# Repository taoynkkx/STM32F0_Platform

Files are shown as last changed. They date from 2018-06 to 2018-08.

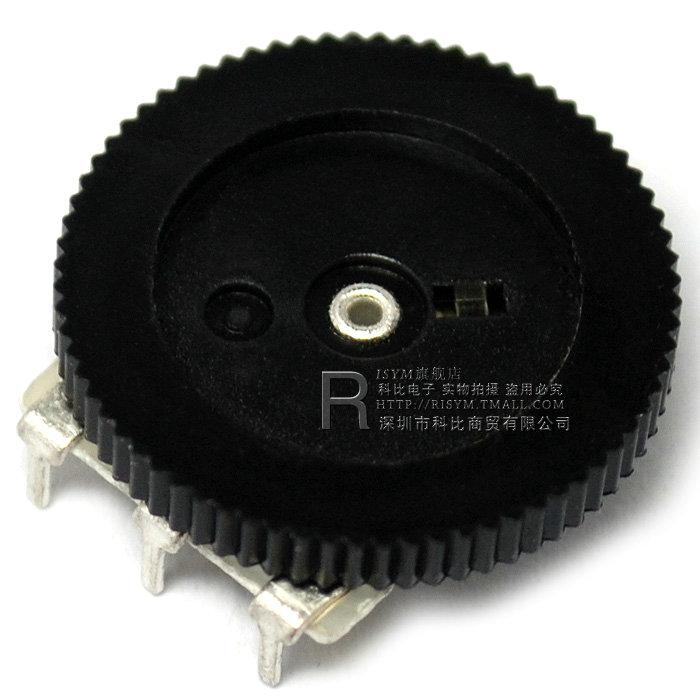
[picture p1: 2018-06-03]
010_Hardware/030_Datasheets/Potentiometer2.jpg

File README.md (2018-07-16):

# STM32F0 Platform

This project begins with designing a simple development board with the chip STM32F072C8T6.

## The platform hardware will include the following peripherals

- 4 buttons: BOOT0, RESET, WAKEUP1, WAKEUP2
- 2 potentiometers (@ ADC_IN8/9)
- 2 crystals: 12MHz, 32.768KHz
- Cell battery
- TF Card (@ SPI1)
- EEPROM (AT24C256 @ IIC1)
- USB-UART converter (PL2303 @ USART1)
- LIN transceiver (TJA1020 @ USART2)
- RS485 transceiver (SP485 @ USART3)
- CAN transceiver (TJA1050 @ CAN)
- USB connector ( @ DP+DM)
- SW debug ports (SWDIO+SWCLK)
- 4 LEDs, with PWM duty control
- 18B20
- not used PINs will be left with connectors

## With these the following features can supported

- STLink connection: SWDIO, SWCLK, RESET
- FlashLoaderDemo: RESET, BOOT0, USART1 or USB(DP+DM)
- Low power mode: WAKEUP1, WAKEUP2
- RTC: cell battery, 32.768KHz crystal
- Backup: cell battery
- USB device.

### Software is going to port all interesting examples from the official library examples, as the first step.

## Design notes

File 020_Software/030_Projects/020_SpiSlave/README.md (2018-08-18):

SPI Slave

This software is to receive data as SPI slave, and then send SPI data to PC via UART.

This is used to analyze the behavior of user software, which is printing run time information from SPI.

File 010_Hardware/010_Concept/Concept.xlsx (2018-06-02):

reset button
boot button

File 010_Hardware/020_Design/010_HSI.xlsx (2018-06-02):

LQFP48 | Pin Name | Pin Type | IO Structure | Notes | AF0 | AF1 | AF2 | AF3 | AF4 | AF5 | AF6 | AF7 | Additional functions | Comments | Use as | Use for | Polarity | LED
1 | VBAT | S |  |  |  |  |  |  |  |  |  |  |  | Backup power supply | VBAT
2 | PC13 | IO | TC | 1,2 |  |  |  |  |  |  |  |  | WKUP2, RTC_TAMP1, RTC_TS, RTC_OUT |  | WKUP2 | Wake Up | High Active
3 | PC14-OSC32_IN(PC14) | IO | TC | 1,2 |  |  |  |  |  |  |  |  | OSC32_IN |  | OSC32_IN
4 | PC15-OSC32_OUT(PC15) | IO | TC | 1,2 |  |  |  |  |  |  |  |  | OSC32_OUT |  | OSC32_OUT
5 | PF0-OSC_IN(PF0) | IO | FT |  |  |  |  |  |  |  |  |  | OSC_IN |  | OSC_IN
6 | PF1-OSC_OUT(PF1) | IO | FT |  |  |  |  |  |  |  |  |  | OSC_OUT |  | OSC_OUT
7 | NRST | IO | RST |  |  |  |  |  |  |  |  |  |  | Device reset input / internal reset output (active low) | Reset
8 | VSSA | S |  |  |  |  |  |  |  |  |  |  |  | Analog ground | GND
9 | VDDA | S |  |  |  |  |  |  |  |  |  |  |  | Analog power supply | VDDA
10 | PA00 | IO | FT |  |  | USART2_CTS | TIM2_CH1_ETR | TSC_G1_IO1 | USART4_TX |  |  | COMP1_OUT | RTC_TAMP2, WKUP1, ADC_IN0, COMP1_INM6 |  | WKUP1 | Wake up | High Active
11 | PA01 | IO | TTa |  | EVENTOUT | USART2_RTS | TIM2_CH2 | TSC_G1_IO2 | USART4_RX | TIM15_CH1N |  |  | ADC_IN1, COMP1_INP
12 | PA02 | IO | TTa |  | TIM15_CH1 | USART2_TX | TIM2_CH3 | TSC_G1_IO3 |  |  |  | COMP2_OUT | ADC_IN2, COMP2_INM6, WKUP4 |  | AF1: TX2 | LIN |  | YES
13 | PA03 | IO | TTa |  | TIM15_CH2 | USART2_RX | TIM2_CH4 | TSC_G1_IO4 |  |  |  |  | ADC_IN3, COMP2_INP |  | AF1: RX2 | LIN
14 | PA04 | IO | TTa |  | SPI1_NSS, I2S1_SW | USART2_CK |  | TSC_G2_IO1 | TIM14_CH1 |  |  |  |  |  |  | SPI
15 | PA05 | IO | TTa |  | SPI1_SCK, I2S1_CK | CEC | TIM2_CH1_ETR | TSC_G2_IO2 |  |  |  |  |  |  |  | SPI
16 | PA06 | IO | TTa |  | SPI1_MISO, I2S1_MCK | TIM3_CH1 | TIM1_BKIN | TSC_G2_IO3 | USART3_CTS | TIM16_CH1 | EVENTOUT | COMP1_OUT |  |  |  | SPI
17 | PA07 | IO | TTa |  | SPI1_MOSI, I2S1_SD | TIM3_CH2 | TIM1_CH1N | TSC_G2_IO4 | TIM14_CH1 | TIM17_CH1 | EVENTOUT | COMP2_OUT |  |  |  | SPI
18 | PB00 | IO | TTa |  | EVENTOUT | TIM3_CH3 | TIM1_CH2N | TSC_G3_IO2 | USART3_CK |  |  |  | ADC_IN8 |  | ADC_IN8 | ADC
19 | PB01 | IO | TTa |  | TIM14_CH1 | TIM3_CH4 | TIM1_CH3N | TSC_G3_IO3 | USART3_RTS |  |  |  | ADC_IN9 |  | ADC_IN9 | ADC
20 | PB02 | IO | FT |  |  |  |  | TSC_G3_IO4
21 | PB10 | IO | FT |  | CEC | I2C2_SCL | TIM2_CH3 | TSC_SYNC | USART3_TX | SPI2_SCK, I2S2_CK |  |  |  |  | AF4: TX3 | RS485 |  | YES
22 | PB11 | IO | FT |  | EVENTOUT | I2C2_SDA | TIM3_CH4 | TSC_G6_IO1 | USART3_RX |  |  |  |  |  | AF4: RX3 | RS485
23 | VSS | S |  |  |  |  |  |  |  |  |  |  |  | Ground | GND
24 | VDD | S |  |  |  |  |  |  |  |  |  |  |  | Digital power supply | VDD
25 | PB12 | IO | FT |  | SPI2_NSS, I2S2_WS | EVENTOUT | TIM1_BKIN | TSC_G6_IO2 | USART3_CK | TIM15_BKIN |  |  |  |  | AF0 | SPI/I2C
26 | PB13 | IO | FTf |  | SPI2_SCK, I2S2_CK |  | TIM1_CH1N | TSC_G6_IO3 | USART3_CTS | I2C2_SCL |  |  |  |  | AF0/AF5 | SPI/I2C
27 | PB14 | IO | FTf |  | SPI2_MISO, I2S2_MCK | TIM15_CH1 | TIM1_CH2N | TSC_G6_IO4 | USART3_RTS | I2C2_SDA |  |  |  |  | AF0/AF5 | SPI/I2C
28 | PB15 | IO | FT |  | SPI2_MOSI, I2S2_SD | TIM15_CH2 | TIM1_CH3N | TIM15_CH1N |  |  |  |  | WKUP7, RTC_REFIN |  | AF0 | SPI/I2C
29 | PA08 | IO | FT | 3 | MCO | USART1_CK | TIM1_CH1 | EVENTOUT | CRS_SYNC
30 | PA09 | IO | FT | 3 | TIM15_BKIN | USART1_TX | TIM1_CH2 | TSC_G4_IO1 |  |  |  |  |  |  | AF1: TX1 | reflash/debug |  | YES
31 | PA10 | IO | FT | 3 | TIM17_BKIN | USART1_RX | TIM1_CH3 | TSC_G4_IO2 |  |  |  |  |  |  | AF1: RX1 | reflash/debug
32 | PA11 | IO | FT | 3 | EVENTOUT | USART1_CTS | TIM1_CH4 | TSC_G4_IO3 | CAN_RX |  |  | COMP1_OUT | USB_DM |  | USB_DM | USB
33 | PA12 | IO | FT | 3 | EVENTOUT | USART1_RTS | TIM1_ETR | TSC_G4_IO4 | CAN_TX |  |  | COMP2_OUT | USB_DP |  | USB_DP | USB
34 | PA13 | IO | FT | 3,4 | SWDIO | IR_OUT | USB_NOE |  |  |  |  |  |  |  | SWDIO | debug
35 | VSS | S |  |  |  |  |  |  |  |  |  |  |  |  | GND
36 | VDDIO2 | S |  |  |  |  |  |  |  |  |  |  |  |  | VDD
37 | PA14 | IO | FT | 3,4 | SWCLK | USART2_TX |  |  |  |  |  |  |  |  | SWCLK | debug
38 | PA15 | IO | FT | 3 | SPI1_NSS, I2S1_WS | USART2_RX | TIM2_CH1_ETR | EVENTOUT | USART4_RTS |  |  |  |  |  | AF0: NSS1 | SFLASH
39 | PB03 | IO | FT |  | SPI1_SCK, I2S1_CK | EVENTOUT | TIM2_CH2 | TSC_G5_IO1 |  |  |  |  |  |  | AF0: SCK1 | SFLASH
40 | PB04 | IO | FT |  | SPI1_MISO, I2S1_MCK | TIM3_CH1 | EVENTOUT | TSC_G5_IO2 |  | TIM17_BKIN |  |  |  |  | AF0: MISO1 | SFLASH
41 | PB05 | IO | FT |  | SPI1_MOSI, I2S1_SD | TIM3_CH2 | TIM16_BKIN | I2C1_SMBA |  |  |  |  | WKUP6 |  | AF0: MOSI1 | SFLASH
42 | PB06 | IO | FT |  | USART1_TX | I2C1_SCL | TIM16_CH1N | TSC_G5_IO3 |  |  |  |  |  |  | AF1: SCL1 | EEP
43 | PB07 | IO | FTf |  | USART1_RX | I2C1_SDA | TIM17_CH1N | TSC_G5_IO4 | USART4_CTS |  |  |  |  |  | AF1: SDA1 | EEP
44 | BOOT0 | I | B |  |  |  |  |  |  |  |  |  |  | Boot memory selection | BOOT | reflash
45 | PB08 | IO | FTf |  | CEC | I2C1_SCL | TIM16_CH1 | TSC_SYNC | CAN_RX |  |  |  |  |  | AF4: CRX | CAN
46 | PB09 | IO | FTf |  | IR_OUT | I2C1_SDA | TIM17_CH1 | EVENTOUT | CAN_TX | SPI2_NSS, I2S2_WS |  |  |  |  | AF4: CTX | CAN |  | YES
47 | VSS | S |  |  |  |  |  |  |  |  |  |  |  | Ground | GND
48 | VDD | S |  |  |  |  |  |  |  |  |  |  |  | Digital power supply | VDD

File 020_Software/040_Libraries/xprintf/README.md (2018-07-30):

This is printf function for microcontroller from elm-chan.org.

Embedded String Functions - http://elm-chan.org/fsw/strf/xprintf.html

This is distributed as Open Source Software. See copyright notice below and
http://elm-chan.org/fsw_e.html.

------------------------------------------------------------------------
  Universal string handler for user console interface
------------------------------------------------------------------------

  Copyright (C) 2011, ChaN, all right reserved.<br>

 * This software is a free software and there is NO WARRANTY.
 * No restriction on use. You can use, modify and redistribute it for personal, non-profit or commercial products UNDER YOUR RESPONSIBILITY.
 * Redistributions of source code must retain the above copyright notice.

-------------------------------------------------------------------------

And xio.h/c is adapted for this project from xprintf.h/c

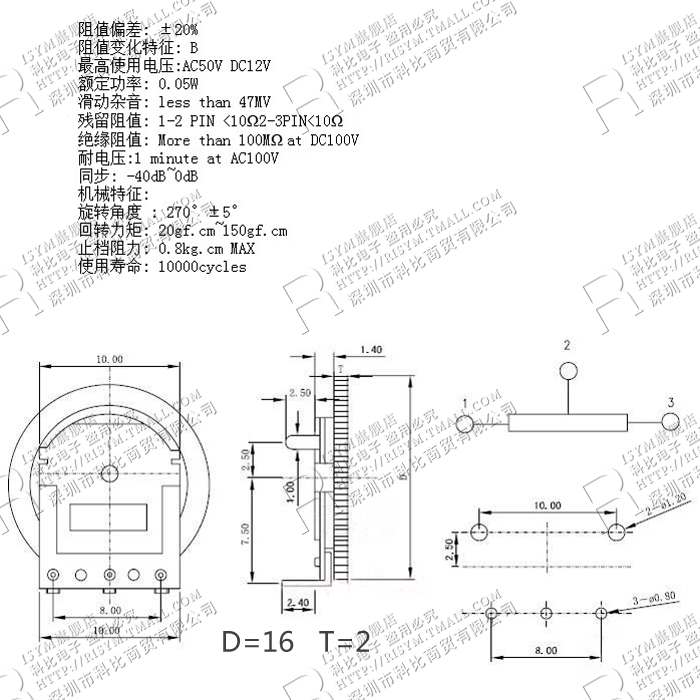
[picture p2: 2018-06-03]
010_Hardware/030_Datasheets/Potentiometer.jpg

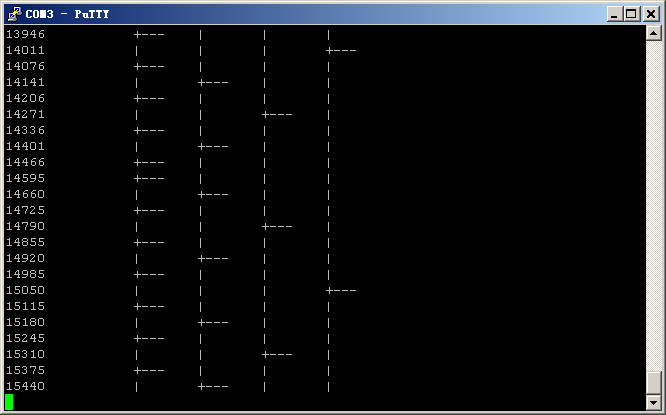
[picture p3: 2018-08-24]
020_Software/030_Projects/000_Template/doc/run.png

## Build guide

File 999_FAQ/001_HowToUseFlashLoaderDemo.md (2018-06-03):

# How to use the official FlashLoaderDemo to download S19/HEX?

- step 1, connect your board via USB(PL) to your computer. (you should have already installed FlashLoaderDemo and PL2303 driver).
- step 2, keep BOOT button pressed, and press RESET button and release RESET, then release BOOT.
- step 3, you should be able to run FlashLoaderDemo and connect to the board.

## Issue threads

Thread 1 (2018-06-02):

[HW] design the schematic and PCB layout.

taoynkkx, 2018-06-02:
Design the schematic and PCB layout.

taoynkkx, 2018-06-03:
split task into new issues: #2, #3, #4, #5.

taoynkkx, 2018-07-21:
done.

Closed 2018-07-21.

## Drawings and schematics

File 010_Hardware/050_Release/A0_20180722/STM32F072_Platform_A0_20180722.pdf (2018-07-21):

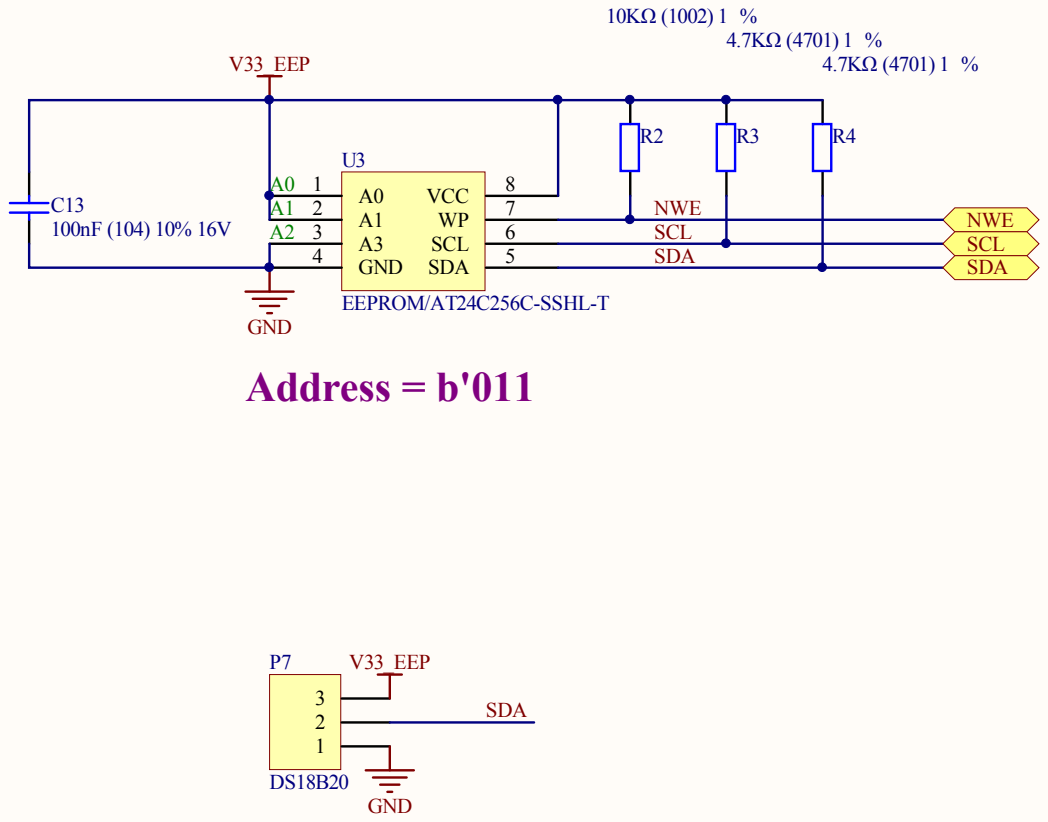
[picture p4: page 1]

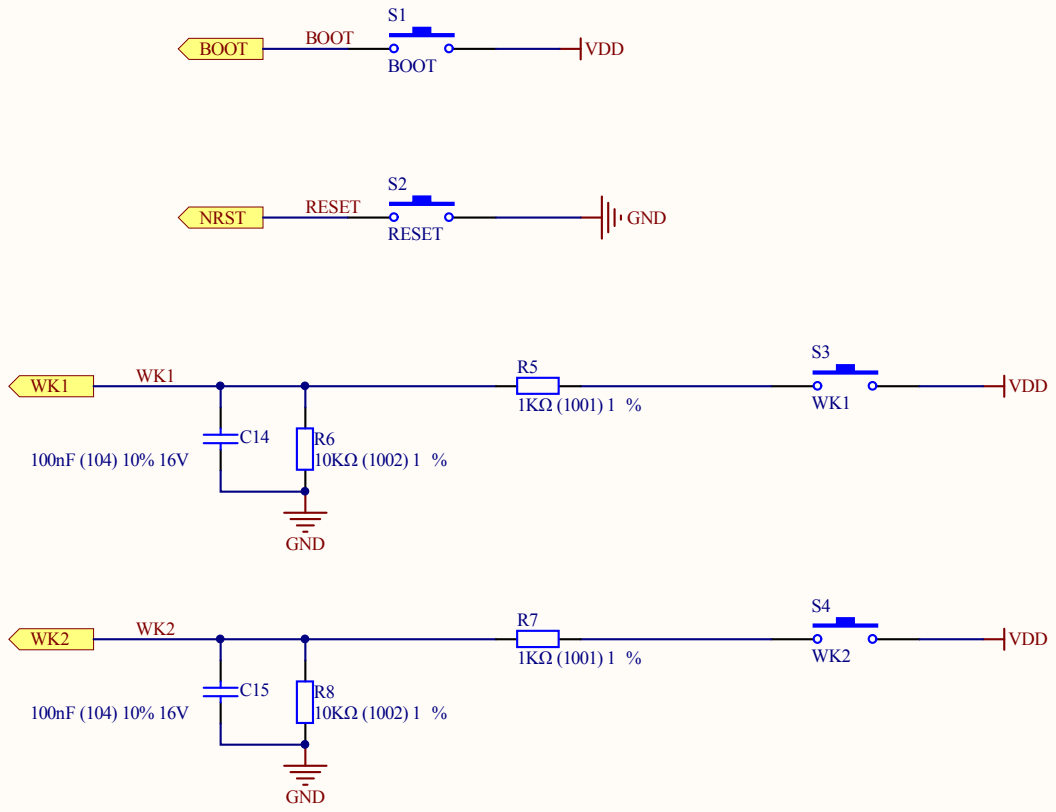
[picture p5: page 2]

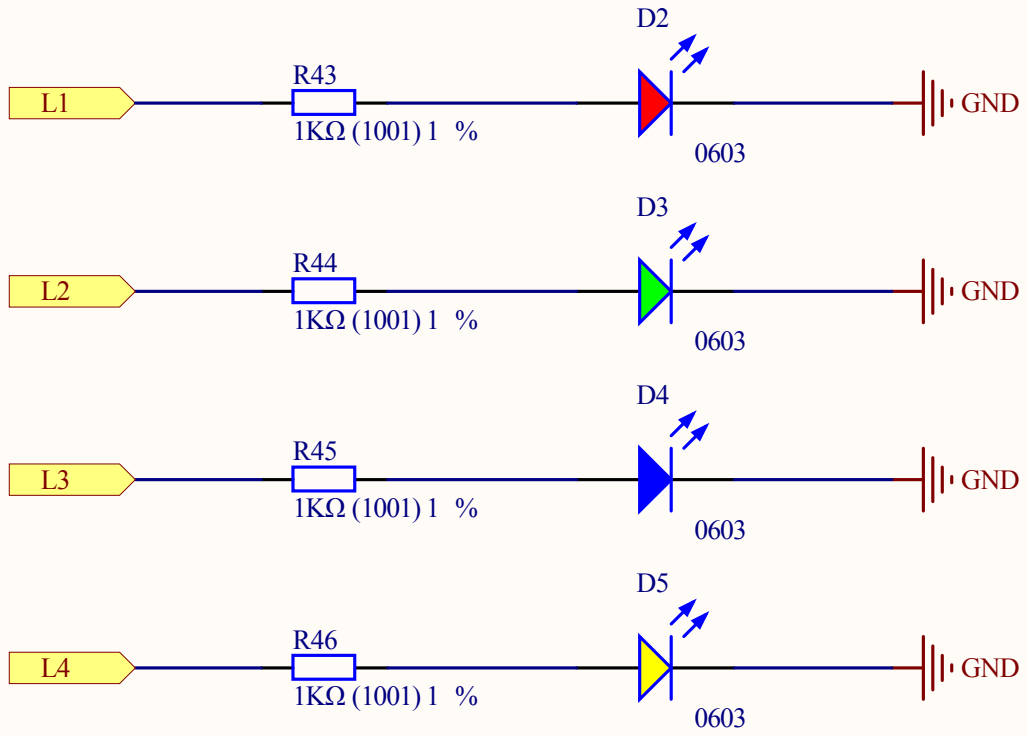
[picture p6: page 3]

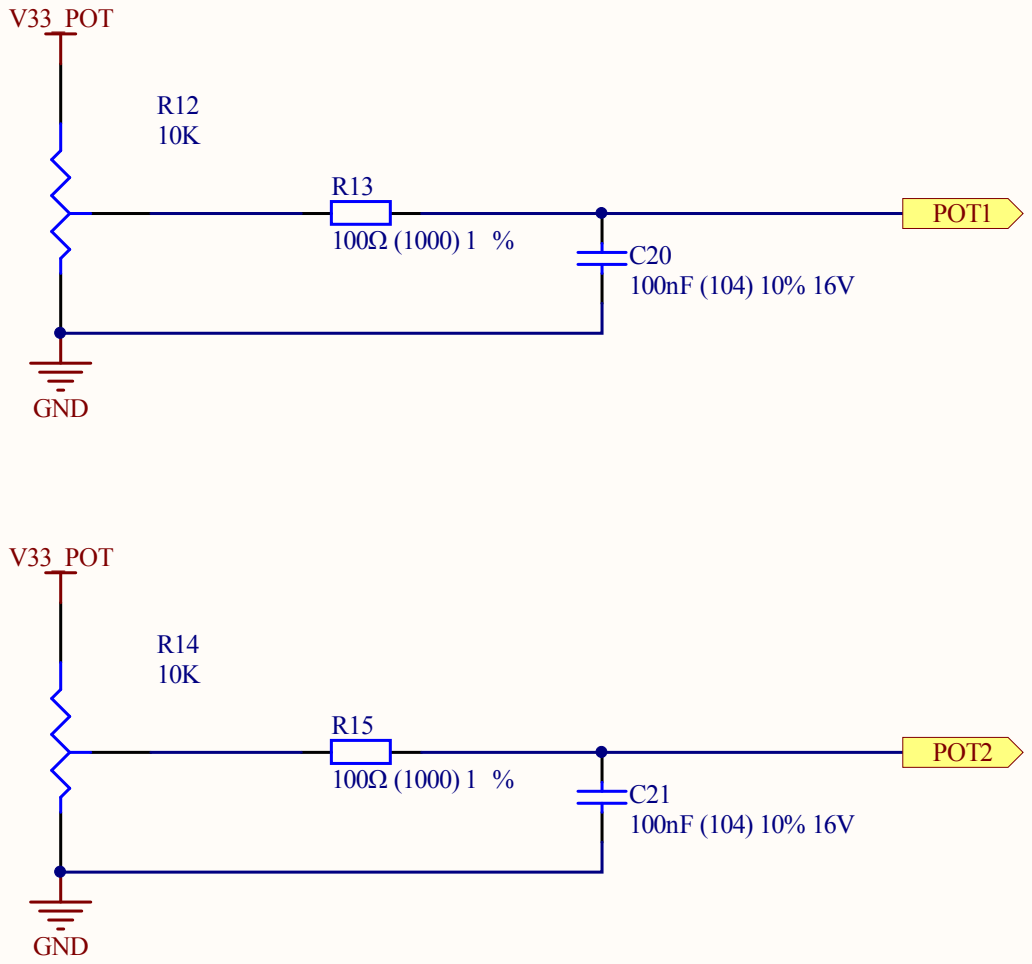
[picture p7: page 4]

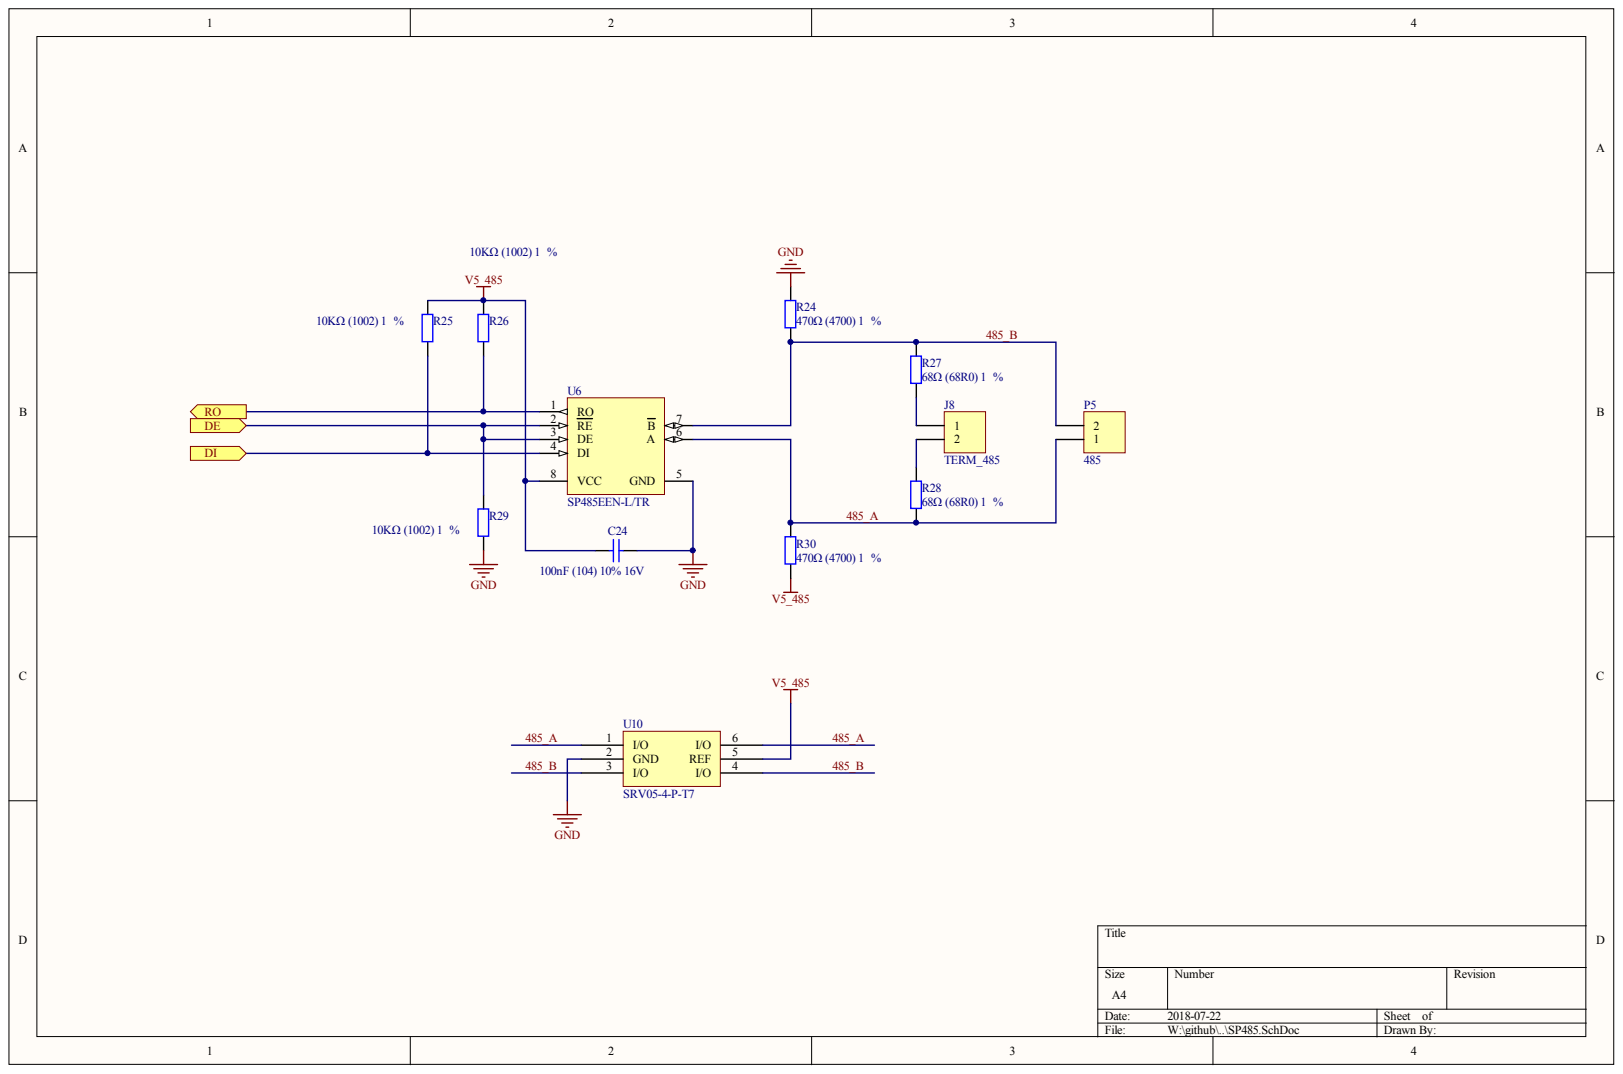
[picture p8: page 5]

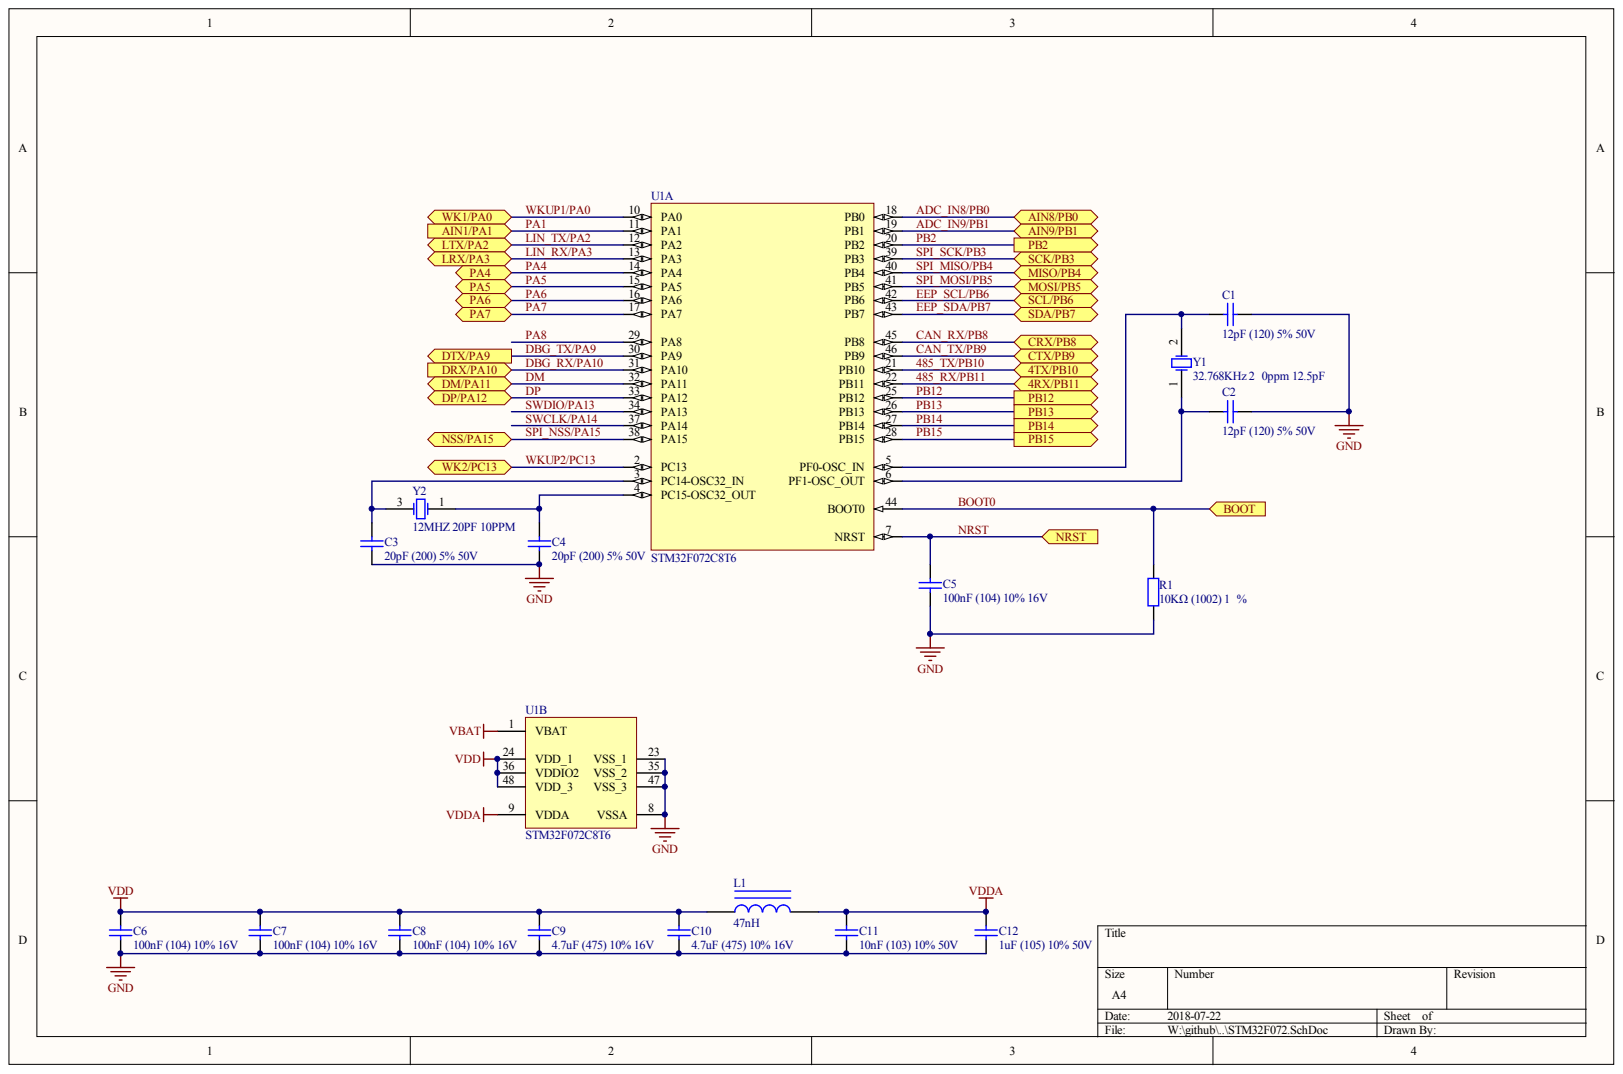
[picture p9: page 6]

CAN_RX/PB8 CRX/PB8 CAN_TX/PB9 4TX/PB10 485_RX/PB11 4RX/PB11 PB12 PB12 PB13 PB13 | 12pF (120) 5% 50V 32.768KHz ¡À2 0ppm 12.5pF

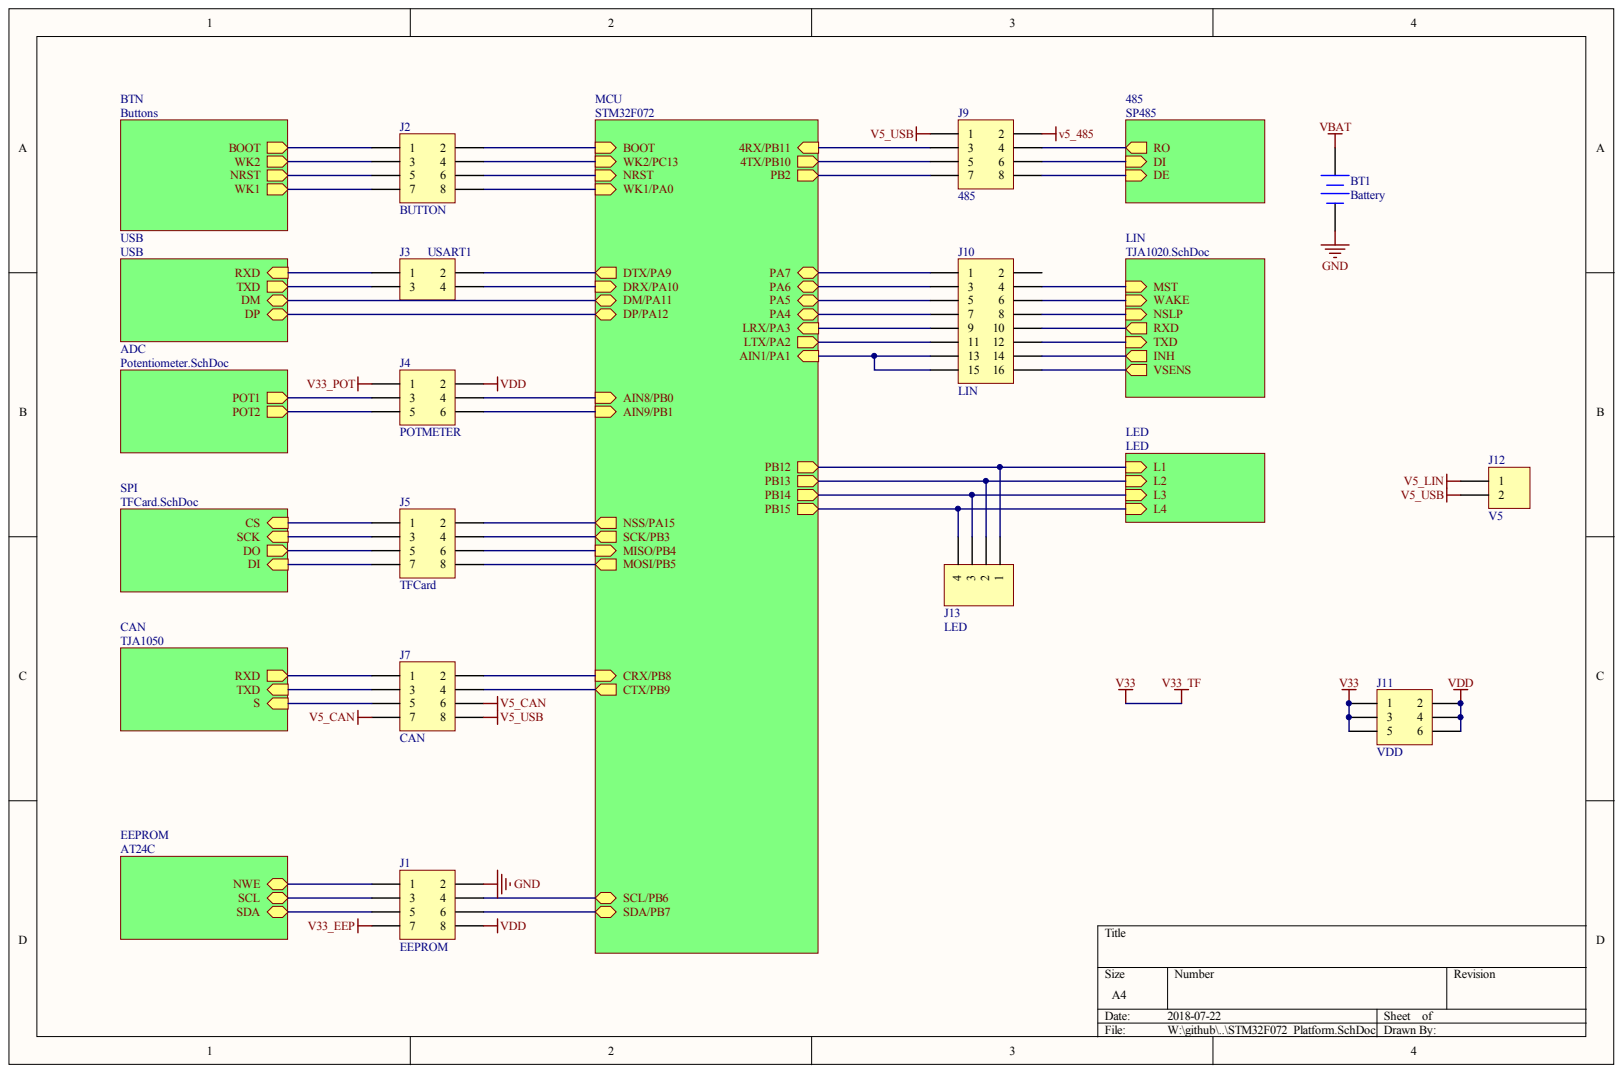
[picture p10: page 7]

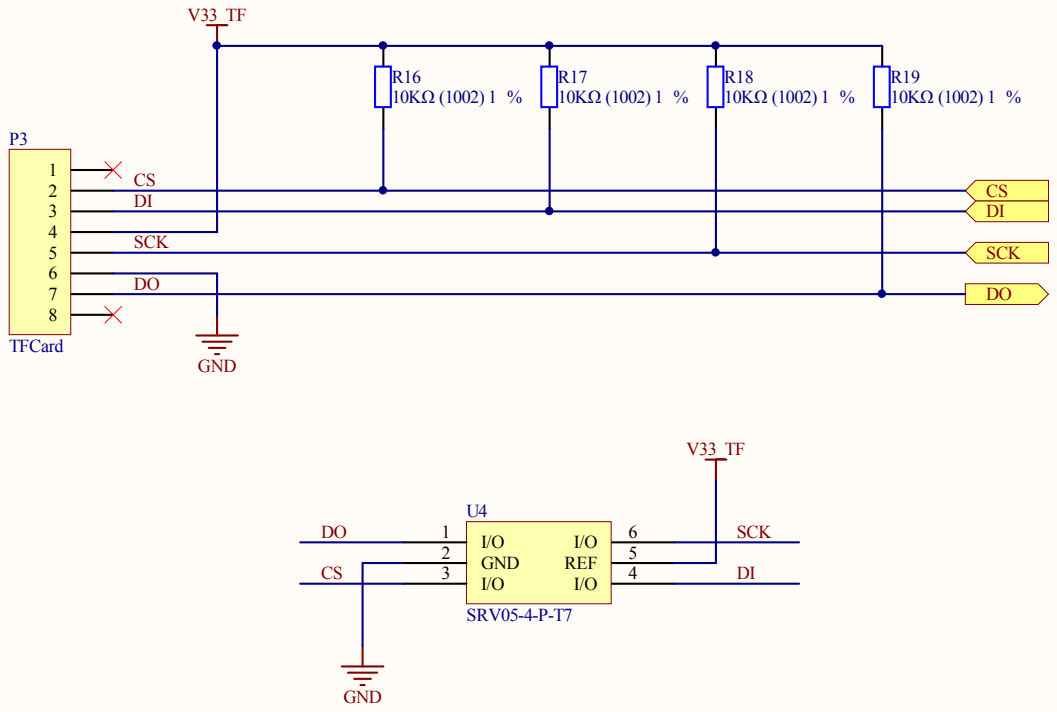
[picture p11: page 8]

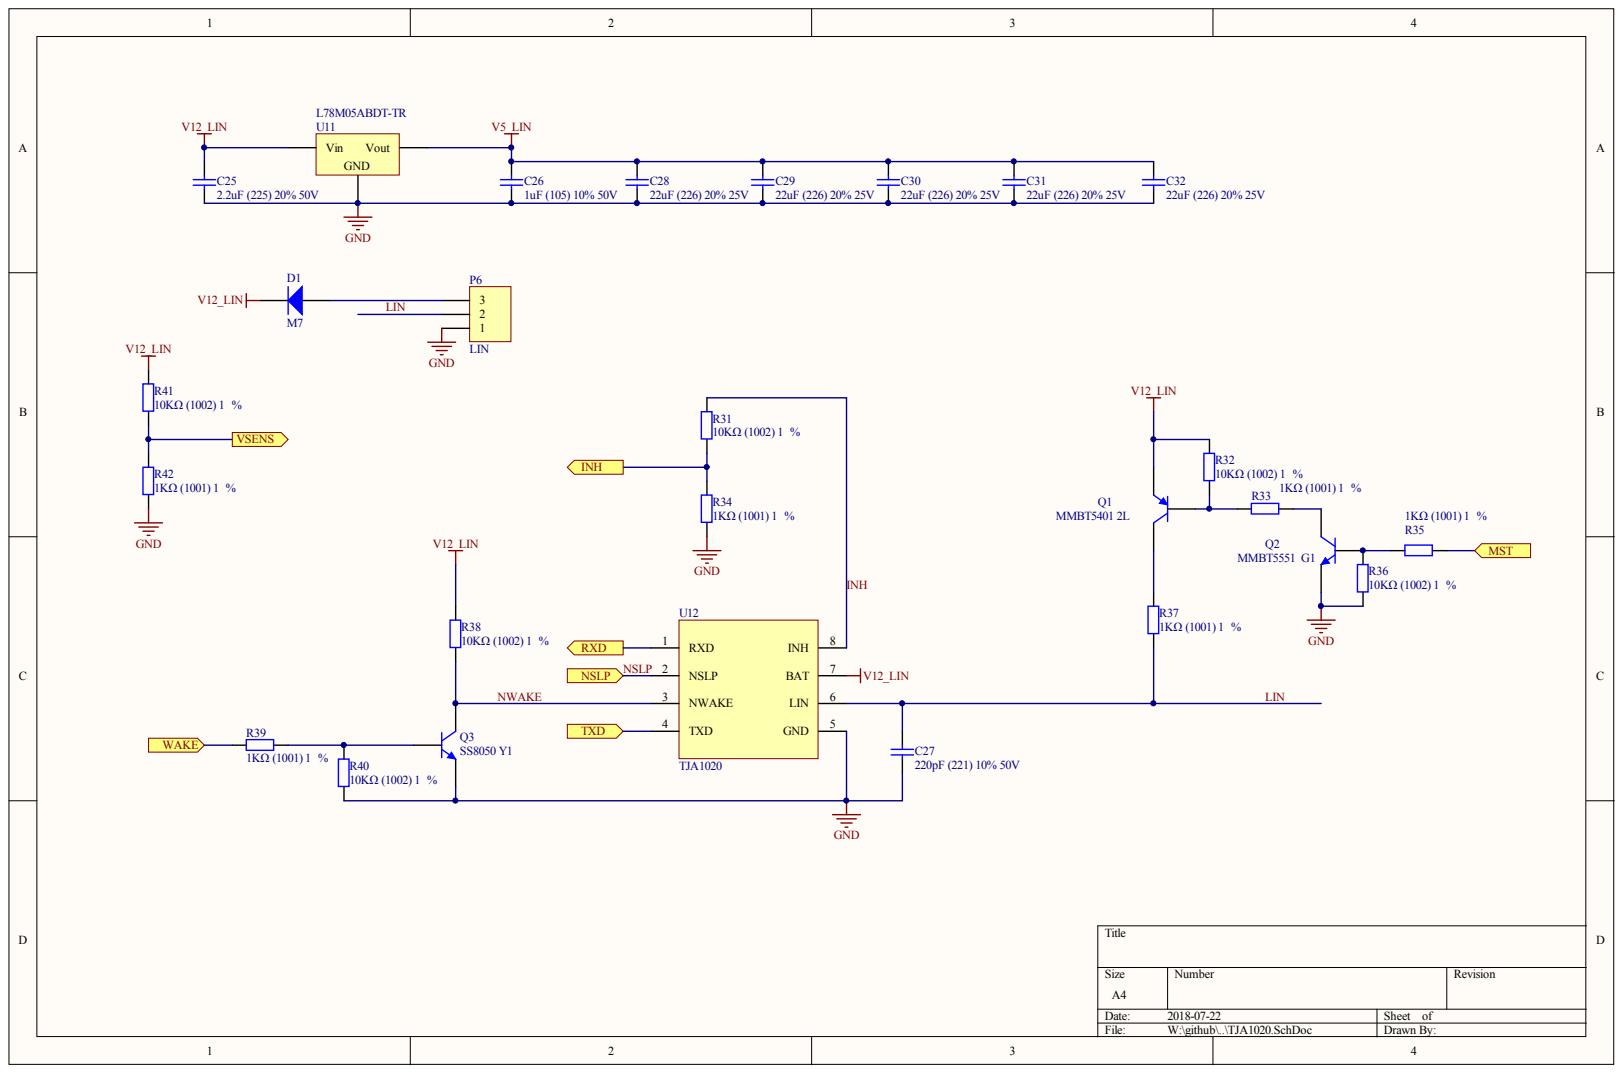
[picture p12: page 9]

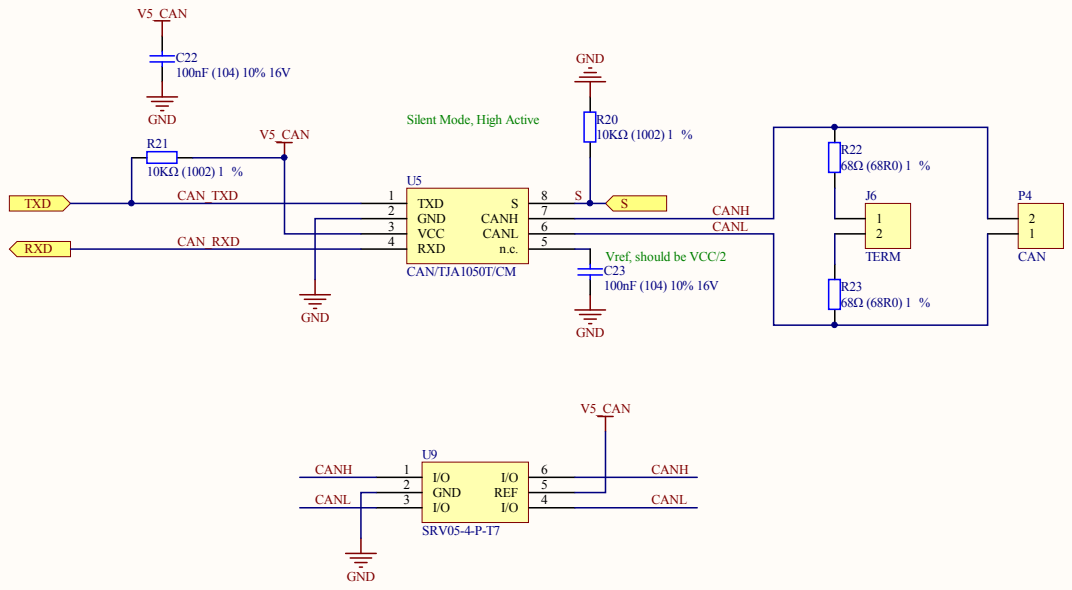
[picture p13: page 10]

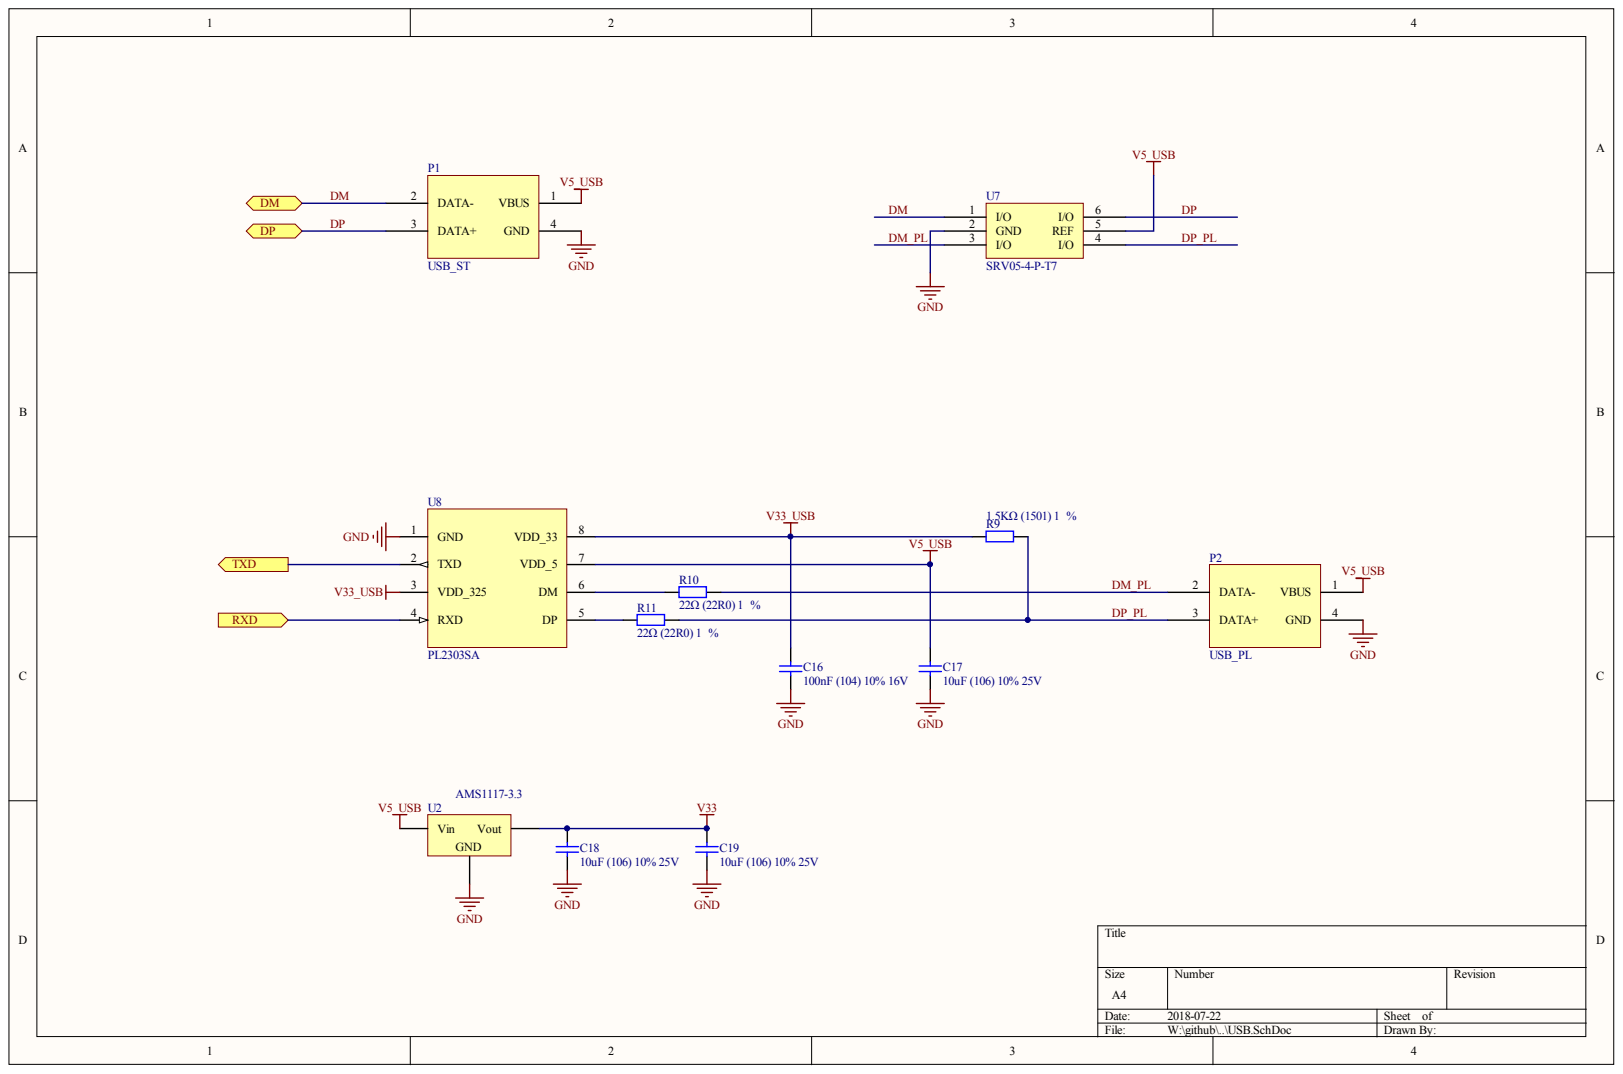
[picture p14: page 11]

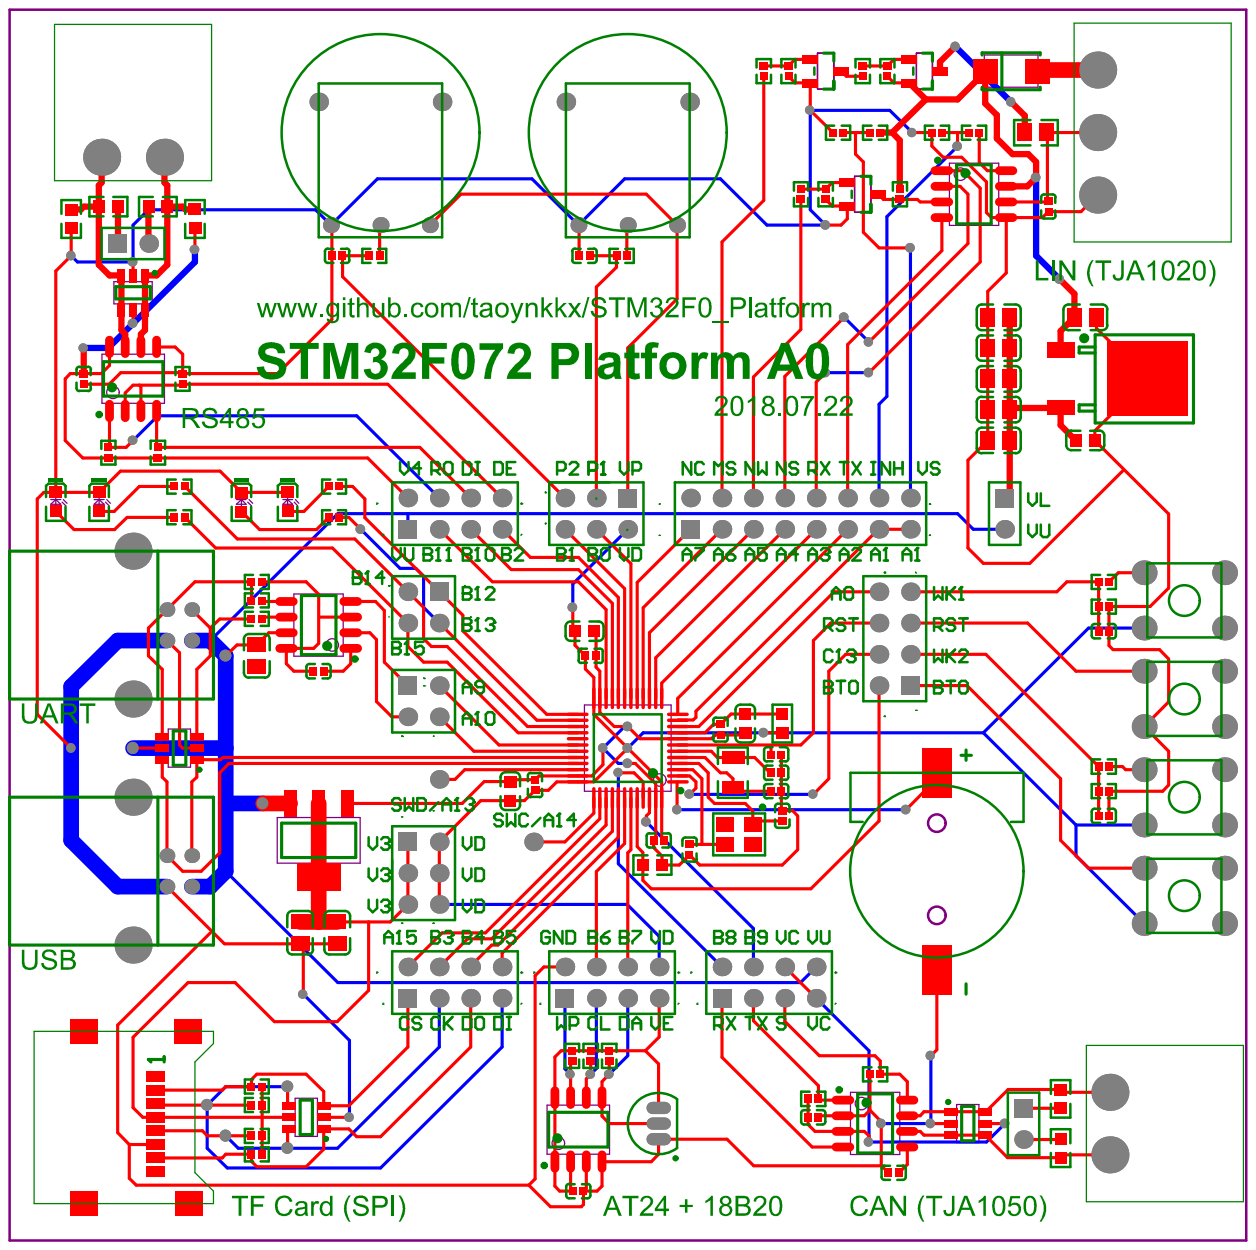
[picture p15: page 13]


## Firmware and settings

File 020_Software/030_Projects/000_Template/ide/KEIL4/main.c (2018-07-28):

/**
  ******************************************************************************
  * @file    Project/STM32F0xx_StdPeriph_Templates/main.c 
  * @author  MCD Application Team
  * @version V1.5.0
  * @date    05-December-2014
  * @brief   Main program body
  ******************************************************************************
  * @attention
  *
  * <h2><center>&copy; COPYRIGHT 2014 STMicroelectronics</center></h2>
  *
  * Licensed under MCD-ST Liberty SW License Agreement V2, (the "License");
  * You may not use this file except in compliance with the License.
  * You may obtain a copy of the License at:
  *
  *        http://www.st.com/software_license_agreement_liberty_v2
  *
  * Unless required by applicable law or agreed to in writing, software 
  * distributed under the License is distributed on an "AS IS" BASIS, 
  * WITHOUT WARRANTIES OR CONDITIONS OF ANY KIND, either express or implied.
  * See the License for the specific language governing permissions and
  * limitations under the License.
  *
  ******************************************************************************
  */

/* Includes ------------------------------------------------------------------*/
#include "taskScheduler/inc/taskScheduler.h"
#include "msp/msp.h"
#include "bsp/bsp.h"

/* Private typedef -----------------------------------------------------------*/
/* Private define ------------------------------------------------------------*/
/* Private macro -------------------------------------------------------------*/
/* Private variables ---------------------------------------------------------*/
/* Private function prototypes -----------------------------------------------*/
/* Private functions ---------------------------------------------------------*/

/**
  * @brief  Main program.
  * @param  None
  * @retval None
  */
int main(void)
{
  // sw initialization
  tasch_init();

  // hw initialization
  msp_init();
  bsp_init();

  // dead loop inside, never get back
  tasch_main();
}

/**
  * @}
  */


/************************ (C) COPYRIGHT STMicroelectronics *****END OF FILE****/

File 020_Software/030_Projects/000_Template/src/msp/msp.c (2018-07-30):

#include "msp.h"
#include "mDIO.h"
#include "stm32f0xx.h"

void msp_xioSend(char c)
{
  USART_SendData(USART1,c);
  while (USART_GetFlagStatus(USART1, USART_FLAG_TXE) == RESET);
}

static void msp_xioInit(void)
{
  USART_InitTypeDef USART_InitStructure;
  GPIO_InitTypeDef GPIO_InitStructure;

  /* Enable GPIO clock */
  RCC_AHBPeriphClockCmd(RCC_AHBPeriph_GPIOA, ENABLE);

  /* Enable USART clock */
  RCC_APB2PeriphClockCmd(RCC_APB2Periph_USART1, ENABLE); 

  /* Connect PA9 to USART1_Tx */
  GPIO_PinAFConfig(GPIOA, GPIO_PinSource9, GPIO_AF_1);

  /* Connect PA10 to USART1_Rx */
  GPIO_PinAFConfig(GPIOA, GPIO_PinSource10, GPIO_AF_1);
  
  /* Configure USART Tx as alternate function push-pull */
  GPIO_InitStructure.GPIO_Pin = GPIO_Pin_9;
  GPIO_InitStructure.GPIO_Mode = GPIO_Mode_AF;
  GPIO_InitStructure.GPIO_Speed = GPIO_Speed_10MHz;
  GPIO_InitStructure.GPIO_OType = GPIO_OType_PP;
  GPIO_InitStructure.GPIO_PuPd = GPIO_PuPd_UP;
  GPIO_Init(GPIOA, &GPIO_InitStructure);
    
  /* Configure USART Rx as alternate function push-pull */
  GPIO_InitStructure.GPIO_Pin = GPIO_Pin_10;
  GPIO_Init(GPIOA, &GPIO_InitStructure);
  
  /* USARTx configured as follow:
  - BaudRate = 115200 baud  
  - Word Length = 8 Bits
  - Stop Bit = 1 Stop Bit
  - Parity = No Parity
  - Hardware flow control disabled (RTS and CTS signals)
  - Receive and transmit enabled
  */
  USART_InitStructure.USART_BaudRate = 115200;
  USART_InitStructure.USART_WordLength = USART_WordLength_8b;
  USART_InitStructure.USART_StopBits = USART_StopBits_1;
  USART_InitStructure.USART_Parity = USART_Parity_No;
  USART_InitStructure.USART_HardwareFlowControl = USART_HardwareFlowControl_None;
  USART_InitStructure.USART_Mode = USART_Mode_Rx | USART_Mode_Tx;

  /* USART configuration */
  USART_Init(USART1, &USART_InitStructure);
    
  /* Enable USART */
  USART_Cmd(USART1, ENABLE);
}

static void msp_tickInit(void)
{
  /* Setup SysTick Timer for 1 msec interrupts.
     ------------------------------------------
    1. The SysTick_Config() function is a CMSIS function which configure:
       - The SysTick Reload register with value passed as function parameter.
       - Configure the SysTick IRQ priority to the lowest value (0x0F).
       - Reset the SysTick Counter register.
       - Configure the SysTick Counter clock source to be Core Clock Source (HCLK).
       - Enable the SysTick Interrupt.
       - Start the SysTick Counter.
    
    2. You can change the SysTick Clock source to be HCLK_Div8 by calling the
       SysTick_CLKSourceConfig(SysTick_CLKSource_HCLK_Div8) just after the
       SysTick_Config() function call. The SysTick_CLKSourceConfig() is defined
       inside the misc.c file.

    3. You can change the SysTick IRQ priority by calling the
       NVIC_SetPriority(SysTick_IRQn,...) just after the SysTick_Config() function 
       call. The NVIC_SetPriority() is defined inside the core_cm0.h file.

    4. To adjust the SysTick time base, use the following formula:
                            
         Reload Value = SysTick Counter Clock (Hz) x  Desired Time base (s)
    
       - Reload Value is the parameter to be passed for SysTick_Config() function
       - Reload Value should not exceed 0xFFFFFF
   */

  SysTick_Config(SystemCoreClock/1000);
}

void msp_init(void)
{
  mDIO_init();
  msp_xioInit();
  msp_tickInit();
}

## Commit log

2018-06-02 #1 design schematic and PCB, ongoing...
    [010_HSI.xlsx, AT24C.SchDoc, Concept.xlsx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]
2018-06-03 #1 update mainly for EEPROM(AT24C)
    [AT24C.SchDoc, PCB_A0.PcbDoc, STM32F072.SchDoc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]
2018-06-03 #1 update schematic pdf file
    [PCB_A0.PcbDoc, STM32F072_Platform.PrjPcb]
2018-06-03 #1 put buttons in another sheet
    [Buttons.SchDoc, PCB_A0.PcbDoc, STM32F072.SchDoc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]
2018-06-03 #1 put USB, PL2303, AMS1117 into USB sheet
    [PCB_A0.PcbDoc, STM32F072.SchDoc, STM32F072_Platform.PrjPcb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]
2018-06-03 #1 update footprint of buttons and battery, update pcb
    [Buttons.SchDoc, PCB_A0.PcbDoc, STM32F072_Platform.SchDoc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]
2018-06-03 #1 add pcb lib for potentiometer and TF card
    [PCB_A0.PcbDoc, Temp.PcbLib]
2018-06-03 #1 add potentiometer
    [PCB_A0.PcbDoc, Potentiometer.SchDoc, STM32F072.SchDoc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]
2018-06-03 #1 add TFcard in sch and pcb
    [PCB_A0.PcbDoc, STM32F072_Platform.PrjPcb, STM32F072_Platform.SchDoc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]
2018-06-03 Update README.md
    change SPI Flash to TF card.
2018-06-03 #3 finish CAN sch and pcb
    [PCB_A0.PcbDoc, STM32F072.SchDoc, STM32F072_Platform.SchDoc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]
2018-06-07 #2 Finish RS485 sch and pcb
    [PCB_A0.PcbDoc, SP485.SchDoc, STM32F072_Platform.SchDoc]
2018-06-20 #4 Add TJA1020 for LIN
    [PCB_A0.PcbDoc, STM32F072.SchDoc, STM32F072_Platform.PrjPcb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]
2018-07-16 #6 done
    [PCB_A0.PcbDoc, STM32F072_Platform.SchDoc]
2018-07-16 #8 done
    [PCB_A0.PcbDoc, STM32F072_Platform.SchDoc, TJA1020.SchDoc]
2018-07-16 #7 done
    [AT24C.SchDoc, PCB_A0.PcbDoc, STM32F072_Platform.SchDoc]
2018-07-16 #1 update connections
    [PCB_A0.PcbDoc, STM32F072.SchDoc, STM32F072_Platform.SchDoc]
2018-07-21 #1 add led, finish connection
    [LED.SchDoc, PCB_A0.PcbDoc, STM32F072.SchDoc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]
2018-07-21 add silks
    [PCB_A0.PcbDoc, STM32F072_Platform.SchDoc]
2018-07-21 #9 done
    [STM32F072_Platform.PrjPcb]
2018-07-28 add stm32f0 standard library version 1.5.0
2018-07-28 add source file
    [STM32F0xx_Clock_Configuration_V1.0.1.xls]
2018-07-28 add UM1717 USB Device Library
2018-07-30 add uart1, and config to xio
2018-08-18 rename 020 demo to 020 spi slave
2018-08-18 copy project from selfTest
    [STM32F0xx_Clock_Configuration_V1.0.1.xls]
2018-08-19 #13 add SPI master for test
2018-08-19 #13 SPI slave, tuning
2018-08-24 #10 improve print content, and update out
2018-11-03 #25 copy 010_SelfTest to 000_Template
    [STM32F0xx_Clock_Configuration_V1.0.1.xls]
